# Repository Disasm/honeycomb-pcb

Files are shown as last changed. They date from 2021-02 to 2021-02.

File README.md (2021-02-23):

# honeycomb

An experimental board with GW1NS-2C FPGA.

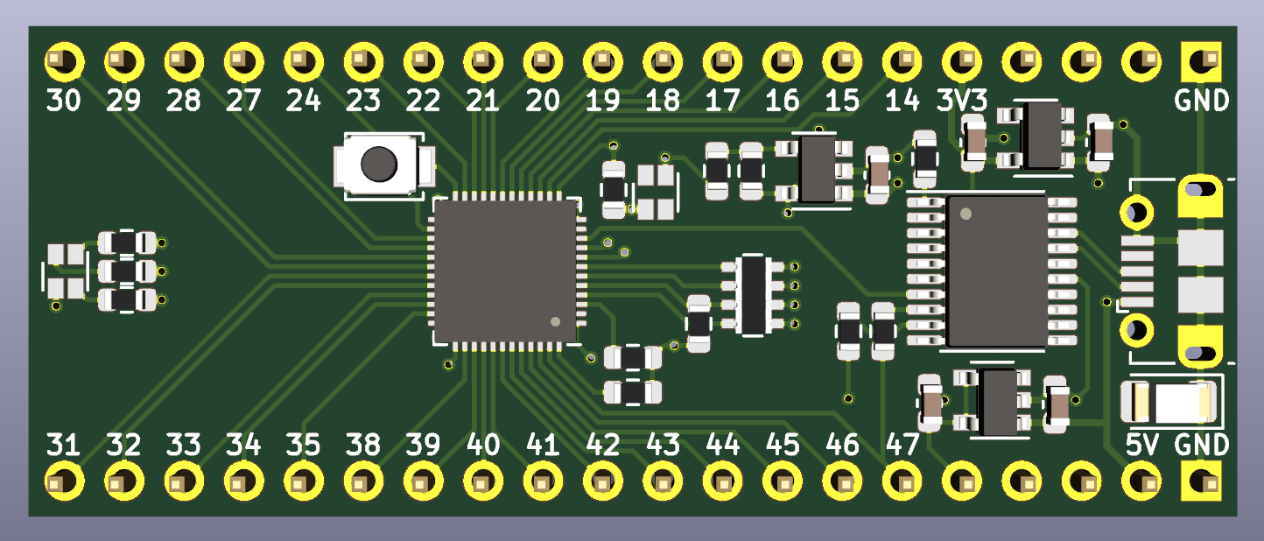
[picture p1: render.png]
PCB render


## Programming

To program the board you need [openFPGALoader](https://github.com/trabucayre/openFPGALoader).

SRAM programming:

```
openFPGALoader -b littleBee -c ft2232 bitstream.fs
```

Internal flash programming:

```
openFPGALoader -b littleBee -c ft2232 -f bitstream.fs
```

## JTAG interface firmware update

To update the firmware you need to reboot into a bootloader:
* Disconnect the board from USB and power supplies.
* Short 3.3V line and the first pin of the STM32F042 MCU.
* While shorting the pin, connect a USB cable.

Then update the firmware with dfu-util:

```
dfu-util -a 0 -s 0x08000000:leave -D firmware.bin
```

## Revision History

### 1.0: 2021-02-19

* First version.
* Errata:
    * 3.3V supply should be used for VCCX instead of 1.8V supply.
    * Power LED is too bright.
    * Resistor values on a schematic do not correspond to the available values.

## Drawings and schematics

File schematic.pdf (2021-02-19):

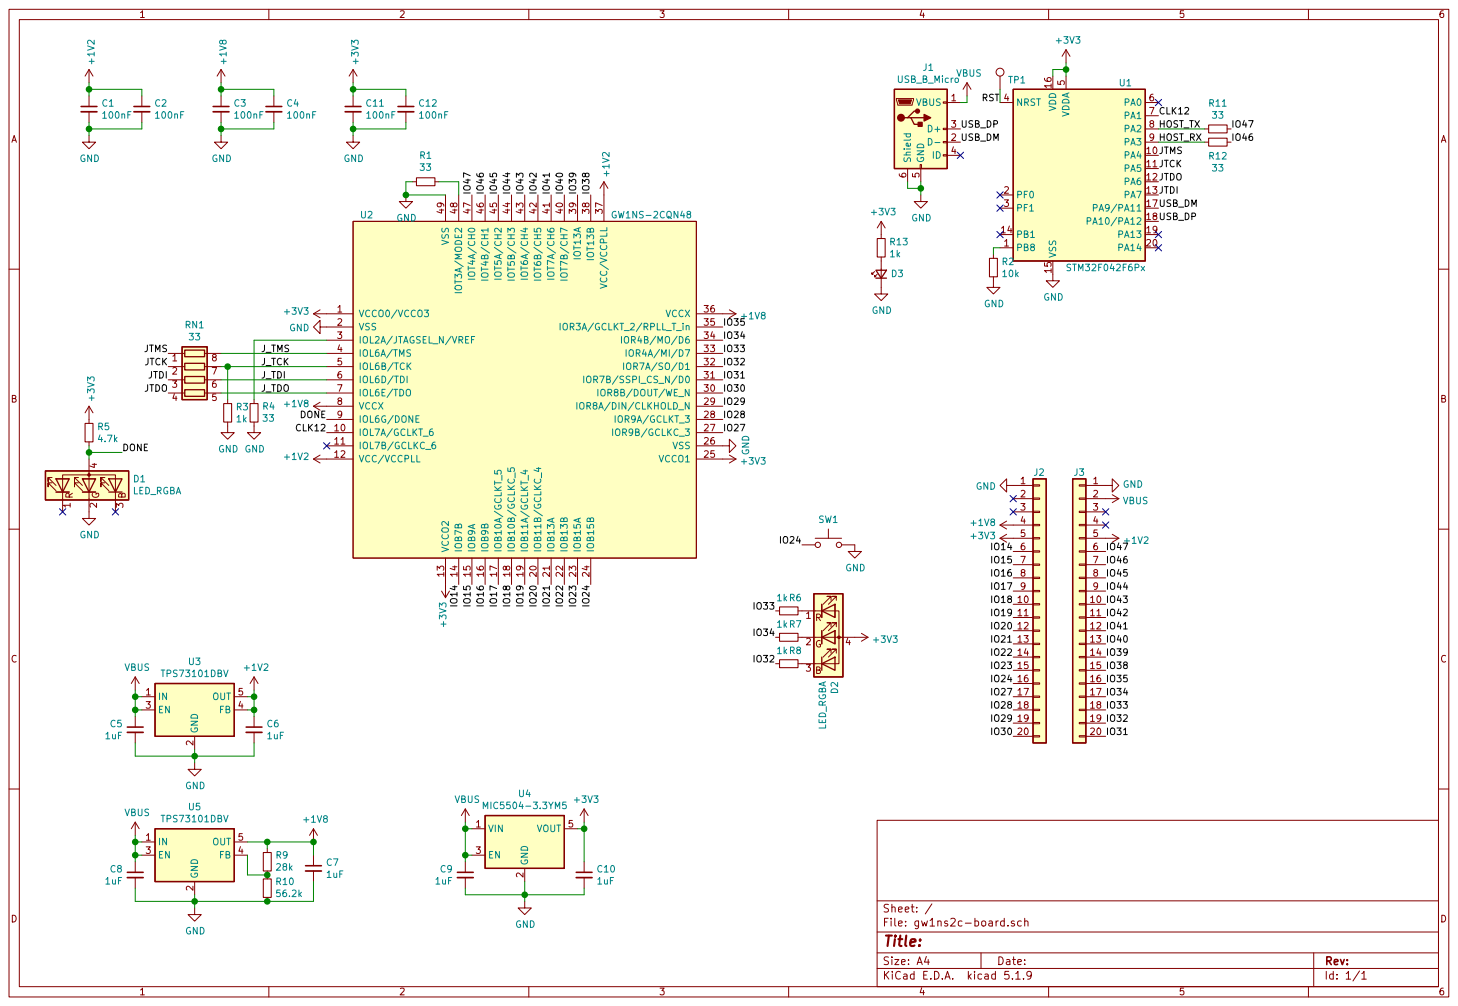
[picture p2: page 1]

2 EN 3 FB 4 OUT 5 U3 TPS73101DBV+1V8 GND

33 GND J_TCK | IOL6B/TCK 5

7 | | J_TDI J_TDO | IOL6D/TDI 6

File: gw1ns2c-board.sch Sheet: /
Id: 1/1 Title:

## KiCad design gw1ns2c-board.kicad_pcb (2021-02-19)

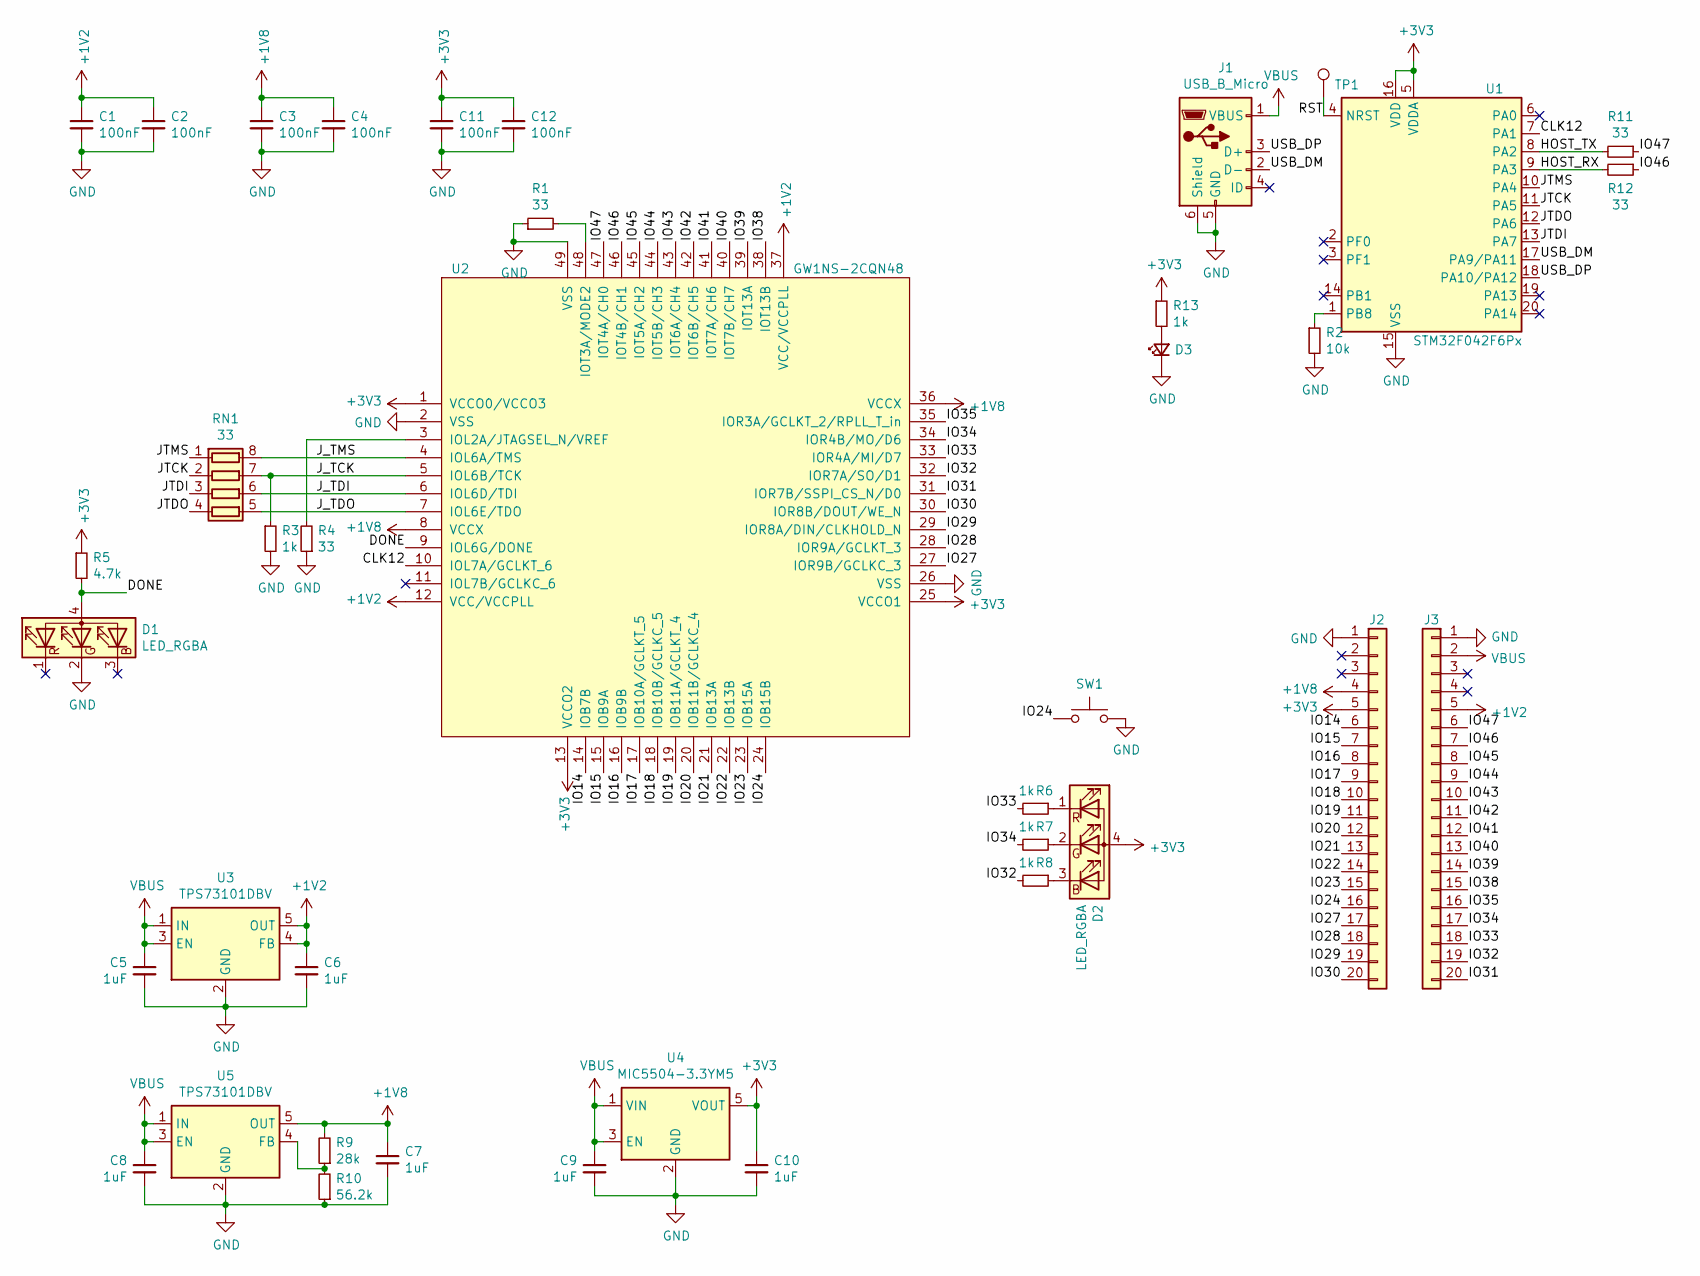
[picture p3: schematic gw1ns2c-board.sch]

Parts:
C1, C2, C3, C4, C11, C12: 100nF; C_0603_1608Metric
C5, C6, C7, C8, C9, C10: 1uF; C_0603_1608Metric
D1, D2: LED_RGBA; LED_LiteOn_LTST-C19HE1WT
D3: LED_Small; LED_1206_3216Metric
J1: USB_B_Micro; USB_Micro-B_Molex-105017-0001
J2, J3: Conn_01x20; PinHeader_1x20_P2.54mm_Vertical
R1, R4, R11, R12: 33; R_0603_1608Metric
R2: 10k; R_0603_1608Metric
R3, R6, R7, R8, R13: 1k; R_0603_1608Metric
R5: 4.7k; R_0603_1608Metric
R9: 28k; R_0603_1608Metric
R10: 56.2k; R_0603_1608Metric
RN1: 33; R_Array_Concave_4x0603
SW1: SW_Push; SW_SPST_B3U-1000P
TP1: TestPoint; TestPoint_Pad_D1.0mm
U1: STM32F042F6Px; TSSOP-20_4.4x6.5mm_P0.65mm
U2: GW1NS-2CQN48; QFN-48-1EP_6x6mm_P0.4mm_EP4.3x4.3mm
U3, U5: TPS73101DBV; SOT-23-5
U4: MIC5504-3.3YM5; SOT-23-5

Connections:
+1V2: C1.1, C2.1, C6.1, J3.5, U2.12 (VCC/VCCPLL), U2.37 (VCC/VCCPLL), U3.4 (FB), U3.5 (OUT)
+1V8: C3.1, C4.1, C7.1, J2.4, R9.2, U2.8 (VCCX), U2.36 (VCCX), U5.5 (OUT)
+3V3: C10.1, C11.1, C12.1, D2.4 (A), J2.5, R5.1, R13.1, U1.5 (VDDA), U1.16 (VDD), U2.1 (VCCO0/VCCO3), U2.13 (VCCO2), U2.25 (VCCO1), U4.5 (VOUT)
/CLK12: U1.7 (PA1), U2.10 (IOL7A/GCLKT_6)
/DONE: D1.4 (A), R5.2, U2.9 (IOL6G/DONE)
/HOST_RX: R12.2, U1.9 (PA3)
/HOST_TX: R11.2, U1.8 (PA2)
/IO14: J2.6, U2.14 (IOB7B)
/IO15: J2.7, U2.15 (IOB9A)
/IO16: J2.8, U2.16 (IOB9B)
/IO17: J2.9, U2.17 (IOB10A/GCLKT_5)
/IO18: J2.10, U2.18 (IOB10B/GCLKC_5)
/IO19: J2.11, U2.19 (IOB11A/GCLKT_4)
/IO20: J2.12, U2.20 (IOB11B/GCLKC_4)
/IO21: J2.13, U2.21 (IOB13A)
/IO22: J2.14, U2.22 (IOB13B)
/IO23: J2.15, U2.23 (IOB15A)
/IO24: J2.16, SW1.1, U2.24 (IOB15B)
/IO27: J2.17, U2.27 (IOR9B/GCLKC_3)
/IO28: J2.18, U2.28 (IOR9A/GCLKT_3)
/IO29: J2.19, U2.29 (IOR8A/DIN/CLKHOLD_N)
/IO30: J2.20, U2.30 (IOR8B/DOUT/WE_N)
/IO31: J3.20, U2.31 (IOR7B/SSPI_CS_N/D0)
/IO32: J3.19, R8.2, U2.32 (IOR7A/SO/D1)
/IO33: J3.18, R6.2, U2.33 (IOR4A/MI/D7)
/IO34: J3.17, R7.2, U2.34 (IOR4B/MO/D6)
/IO35: J3.16, U2.35 (IOR3A/GCLKT_2/RPLL_T_in)
/IO38: J3.15, U2.38 (IOT13B)
/IO39: J3.14, U2.39 (IOT13A)
/IO40: J3.13, U2.40 (IOT7B/CH7)
/IO41: J3.12, U2.41 (IOT7A/CH6)
/IO42: J3.11, U2.42 (IOT6B/CH5)
/IO43: J3.10, U2.43 (IOT6A/CH4)
/IO44: J3.9, U2.44 (IOT5B/CH3)
/IO45: J3.8, U2.45 (IOT5A/CH2)
/IO46: J3.7, R12.1, U2.46 (IOT4B/CH1)
/IO47: J3.6, R11.1, U2.47 (IOT4A/CH0)
/JTCK: RN1.2 (R2.1), U1.11 (PA5)
/JTDI: RN1.3 (R3.1), U1.13 (PA7)
/JTDO: RN1.4 (R4.1), U1.12 (PA6)
/JTMS: RN1.1 (R1.1), U1.10 (PA4)
/J_TCK: R3.1, RN1.7 (R2.2), U2.5 (IOL6B/TCK)
/J_TDI: RN1.6 (R3.2), U2.6 (IOL6D/TDI)
/J_TDO: RN1.5 (R4.2), U2.7 (IOL6E/TDO)
/J_TMS: RN1.8 (R1.2), U2.4 (IOL6A/TMS)
/RST: TP1.1, U1.4 (NRST)
/USB_DM: J1.2 (D-), U1.17 (PA9/PA11)
/USB_DP: J1.3 (D+), U1.18 (PA10/PA12)
GND: C1.2, C2.2, C3.2, C4.2, C5.2, C6.2, C7.2, C8.2, C9.2, C10.2, C11.2, C12.2, D1.2 (GK), D3.1 (K), J1.5 (GND), J1.6 (Shield), J2.1, J3.1, R1.1, R2.2, R3.2, R4.1, R10.1, SW1.2, U1.15 (VSS), U2.2 (VSS), U2.26 (VSS), U2.49 (VSS), U3.2 (GND), U4.2 (GND), U5.2 (GND)
unnamed: D2.1 (RK), R6.1
unnamed: D2.2 (GK), R7.1
unnamed: D2.3 (BK), R8.1
unnamed: D3.2 (A), R13.2
unnamed: R1.2, U2.48 (IOT3A/MODE2)
unnamed: R2.1, U1.1 (PB8)
unnamed: R4.2, U2.3 (IOL2A/JTAGSEL_N/VREF)
unnamed: R9.1, R10.2, U5.4 (FB)
VBUS: C5.1, C8.1, C9.1, J1.1 (VBUS), J3.2, U3.1 (IN), U3.3 (EN), U4.1 (VIN), U4.3 (EN), U5.1 (IN), U5.3 (EN)

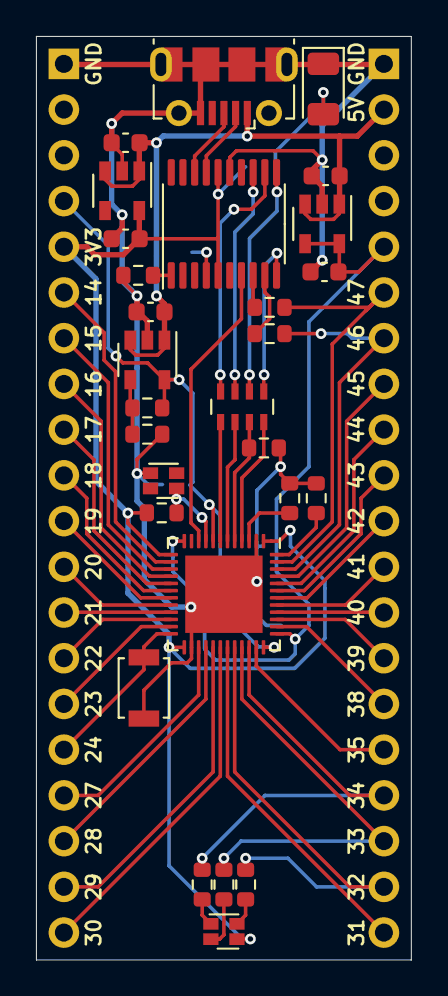
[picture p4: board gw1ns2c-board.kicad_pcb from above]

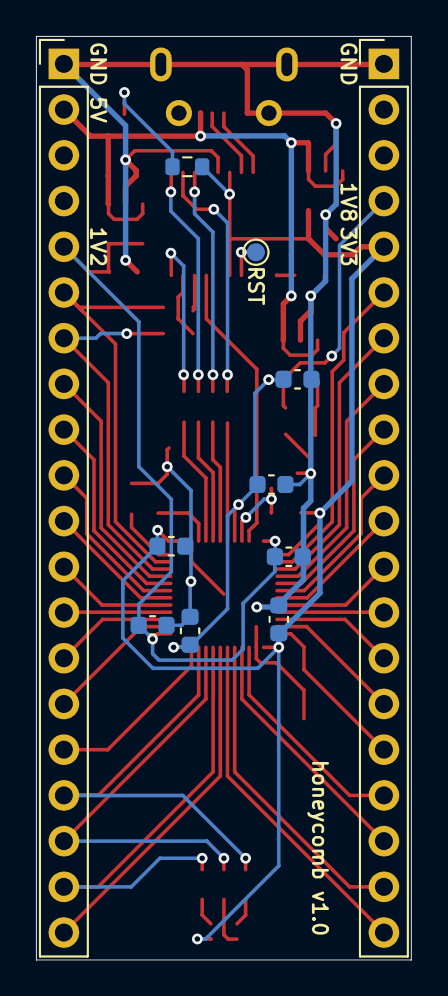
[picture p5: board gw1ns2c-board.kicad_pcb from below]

Board: 2 copper layers, 20.8 x 51.3 mm, 39 parts (11 on the bottom side), 58 nets.

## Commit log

2021-02-19 Add board schematics and layout
    [gw1ns2c-board.kicad_pcb, gw1ns2c-board.sch]
2021-02-19 Add gerbers
    [gw1ns2c-board-B_Cu.gbl, gw1ns2c-board-B_Mask.gbs, gw1ns2c-board-B_SilkS.gbo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]
2021-02-19 Generate Interactive BOM
2021-02-19 Generate schematic PDF
2021-02-19 Add post-assembly notes
    [gw1ns2c-board.sch]
2021-02-23 Add PCB render
